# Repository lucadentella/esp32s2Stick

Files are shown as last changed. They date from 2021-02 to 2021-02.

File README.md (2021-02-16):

# esp32s2Stick
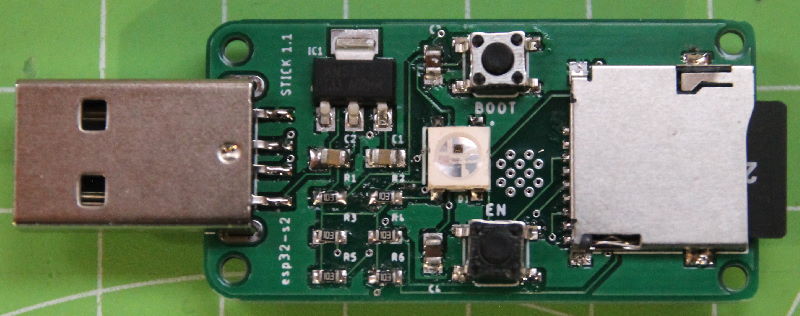
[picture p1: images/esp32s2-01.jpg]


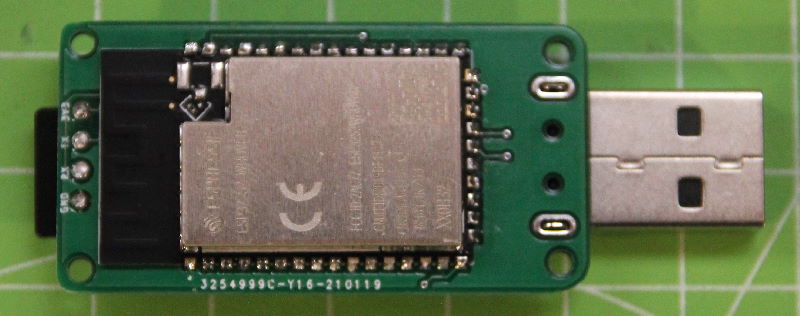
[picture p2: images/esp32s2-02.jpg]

## Description
esp32s2Stick is a USB device based on the **esp32-s2** chip by [Espressif](https://www.espressif.com/en/products/socs/esp32-s2).
Thanks to the presence of an USB OTG interface, it is possible to program the chip to act as a USB peripheral (*mass storage device*, *CDC*...) and to upgrade the firmware through USB (DFU, *Device Firmware Upgrade*).

In addition to the basic circuit needed to run the WROVER module, esp32s2Stick offers an **RGB LED** and a socket for **MicroSD** cards.
## How to make
- Blog post on [my website](http://www.lucadentella.it/en/2021/02/16/esp32s2stick/)
- Eagle files (schematic and board) are available in the "**eagle**" subfolder
- Some test *sketches* for Arduino are available in the "**arduino**" subfolder
- PCB can be ordered [from PCBWay](https://www.pcbway.com/project/shareproject/esp32s2Stick.html)
## Partlist 
 - **C1, C2**: 100nF SMD capacitor (0805)
 - **C3, C4**: 1uF SMD capacitor (0805)
 - **R1, R2, R3, R4, R5, R6**: 10Kohm SMD resistor (0603)
 - **IC1**: 1117-3.3 voltage regulator
 - **D1**: WS2812 RGB led (5050, 4 pins)
 - **BOOT, EN**: SMD momentary switch (5.2mm)
 - **U1**: ESP32-S2-WROVER
 - **J1**: USB A male SMD connector
 - **P1**: MicroSD card socket

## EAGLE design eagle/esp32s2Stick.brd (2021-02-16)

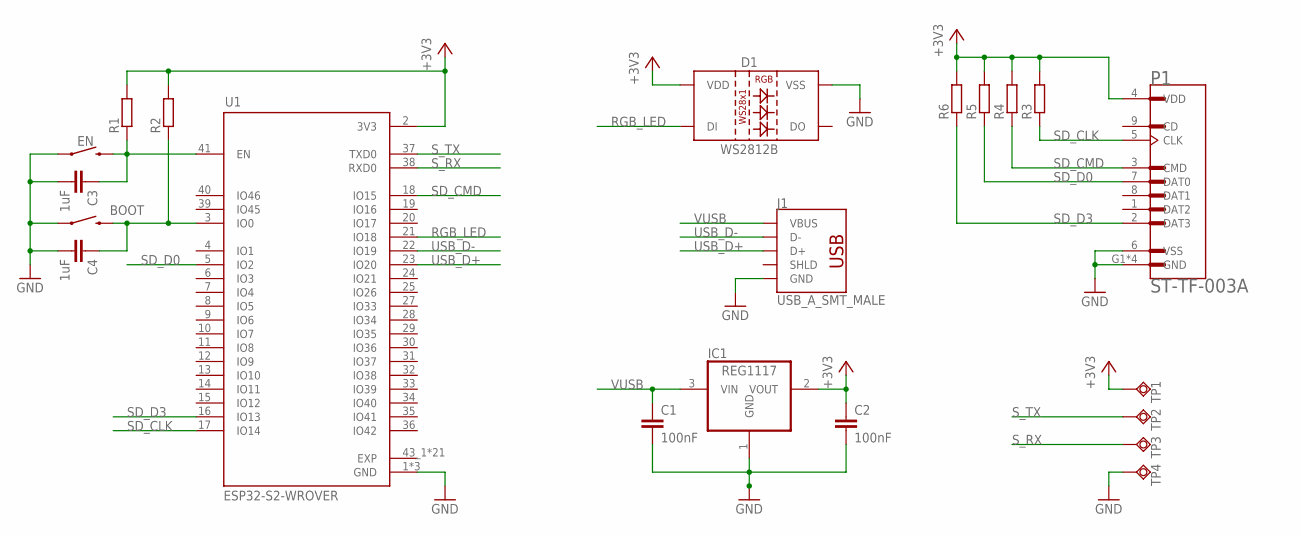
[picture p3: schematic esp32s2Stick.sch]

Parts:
BOOT: MOMENTARY-SWITCH-SPST-SMD-5.2MM; TACTILE_SWITCH_SMD_5.2MM
C1, C2: 100nF; C0805
C3, C4: 1uF; C0805
D1: WS2812B
EN: MOMENTARY-SWITCH-SPST-SMD-5.2MM; TACTILE_SWITCH_SMD_5.2MM
IC1: REG1117; SOT223
J1: USB_A_SMT_MALE; USB-A-SMT-MALE
P1: ST-TF-003A; SUNTECH_ST-TF-003A
R1, R2, R3, R4, R5, R6: R-EU_R0603; R0603
TP1, TP2, TP3, TP4: TPSQTP15R; TP15R
U1: ESP32-S2-WROVER; MODULE_ESP32-S2-WROVER

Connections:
+3V3: C2.1, D1.1 (VDD), IC1.2 (VOUT), P1.4 (VDD), R1.2, R2.2, R3.2, R4.2, R5.2, R6.2, TP1.TP, U1.2 (3V3)
EXP: U1.43_1 (EXP), U1.43_2 (EXP), U1.43_3 (EXP), U1.43_4 (EXP), U1.43_5 (EXP), U1.43_6 (EXP), U1.43_7 (EXP), U1.43_8 (EXP), U1.43_9 (EXP), U1.43_10 (EXP), U1.43_11 (EXP), U1.43_12 (EXP), U1.43_13 (EXP), U1.43_14 (EXP), U1.43_15 (EXP), U1.43_16 (EXP), U1.43_17 (EXP), U1.43_18 (EXP), U1.43_19 (EXP), U1.43_20 (EXP), U1.43_21 (EXP)
GND: BOOT.1, C1.2, C2.2, C3.2, C4.2, D1.3 (VSS), EN.1, IC1.1 (GND), J1.GND1 (GND), P1.6 (VSS), P1.G1 (GND), P1.G2 (GND), P1.G3 (GND), P1.G4 (GND), TP4.TP, U1.1 (GND), U1.26 (GND), U1.42 (GND)
unnamed: BOOT.3 (2), C4.1, R2.1, U1.3 (IO0)
unnamed: C3.1, EN.3 (2), R1.1, U1.41 (EN)
RGB_LED: D1.4 (DI), U1.21 (IO18)
SD_CLK: P1.5 (CLK), R3.1, U1.17 (IO14)
SD_CMD: P1.3 (CMD), R4.1, U1.18 (IO15)
SD_D0: P1.7 (DAT0), R5.1, U1.5 (IO2)
SD_D3: P1.2 (DAT3), R6.1, U1.16 (IO13)
S_RX: TP3.TP, U1.38 (RXD0)
S_TX: TP2.TP, U1.37 (TXD0)
USB_D+: J1.D+1 (D+), U1.23 (IO20)
USB_D-: J1.D-1 (D-), U1.22 (IO19)
VUSB: C1.1, IC1.3 (VIN), J1.VBUS1 (VBUS)

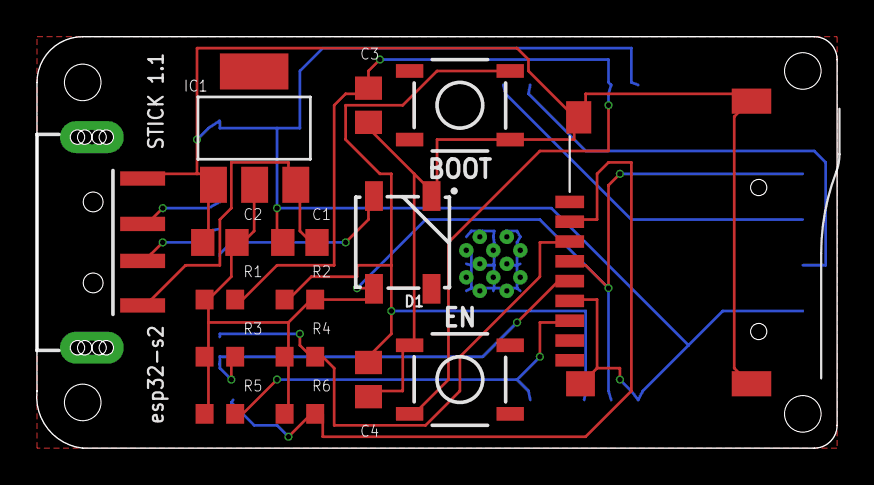
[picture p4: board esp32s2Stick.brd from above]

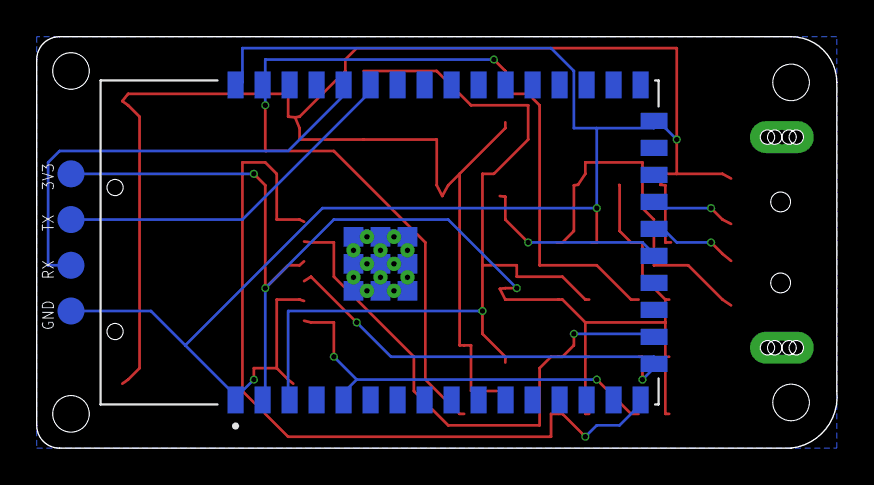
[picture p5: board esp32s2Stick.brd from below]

Board: 2 copper layers, 44.5 x 22.9 mm, 21 parts (5 on the bottom side), 15 nets.

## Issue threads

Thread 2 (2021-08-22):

REQUEST: Being able to order this fully assembled would be great!

Misterke, 2021-08-22:
Ordering the PCB, still leaves sourcing all components and then having to mount them.  I would love a couple of devices like this, but don't have the components, nor the tools or skills for SMD mounting.  So, having a design that could be ordered with all the SMD parts already soldered on and other components added to the package as offered by a.o. JLC PCB, could really help.  Or perhaps a Chinese partner producing an end-user product giving you a cut?

lucadentella, 2021-08-23:
Hi! Thanks for your comment... In the past I worked with some PCBA services but the minimum quantity was 20-30 pcs and honestly at the moment I don't have requests for pre-assembled boards (excluding your one ;) )

I checked with JLCPCB but they don't provide a "market", where I may upload design files, BoM... and let other users order my products. I may upload all the files required to order the boards directly using JLCPCB PCBA service, but be prepared because at least two components (the esp module and the usb connector) are "extended parts" and they require an extra fee to include them in your order... If you like, I may work on this tomorrow

sbhamad, 2022-06-18:
any update on the BoM? i would love to get the exact components to order the pcb myself.

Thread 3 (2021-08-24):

Code for complete

noorhaq, 2021-08-24:
Hi in the arduino part I can see the testing codes but not the code, which will actually make it work. Like PC and SD card will be accessible

lucadentella, 2021-08-25:
Hi! Please consider this project as a "devboard", not a final product. This is the reason why you can't find a code for a specific behavior... you can develop your own code (starting from my example but also using the "plain" esp framework) for your goal.
I know some users who worked on a code to simulate a keyboard and let the device "type" the content of a file on the SD or other users who implemented a "bridge" between a TCP socket and mouse movements.

Closed 2021-08-25.

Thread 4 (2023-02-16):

Ordered a couple of these from PCBWay, they don't seem to power up

cieslicki, 2023-02-16:
Edited: I think I got shipped a bad batch of USB connectors, or there is some PCB trace issue with power coming out of the connector. I soldered jumpers on power and ground to the debug pads, and then also directly to the D+/D- pins coming out of the connector, and it powers up and programs. But then after I program it and plug it back in with the regular connector, it won't power up.

original:

When I plug the device in, there is no indication it is powered up by the LED. Also the voltage regulator is cold. When I attempt to put it into DFU mode with the buttons, the Arduino IDE doesn't see it. I don't think these work at all. Maybe it is an assembly issue.

What is the expected behavior when the device gets plugged in?

lucadentella, 2023-02-16:
Hi

I only ordered PCBs from PCBWay so I can't tell how good they are in assembling the device. It definetly sounds an issue with their USB connector even if it's a very simple part (compared to the new USB-C connectors)

Let me know how it goes, did you try to replace the connector?

cieslicki, 2023-02-19:
Hi.

After further investigation I can say it's definitely not the connector that is the source of the problem.

1) I can plug it in and use a multimeter to read 5v from PWR to GND from the connector pins where they attach to the board.

2) I soldered an external LM1117 voltage regulator onto the debug pins, and ran jumpers back to 5v and GND at the connector pins, the module will power up and program with the board's main USB-A connector plugged into my laptop. So all four connector pins work.

I would say the board at least has power issues. For example, I don't see either a trace or a via at the connector ground pin. So I don't know that the board grounds, and I suspect it does not. I soldered in a jumper from the on-board voltage regulator ground to the connector ground, and it still did not fire up the board, so there are likely a collection of grounding issues.

I tried a couple of different jumper configurations to try to get the on-board voltage regulator to power the module, but nothing I tried worked there.

It's a cool idea to get the SD card reader on a board with the ESP, and with the additional voltage regulator I might still be able to test out the SD functionality, but out of the box as it is right now the board is not really viable as far as I can tell. Additionally with the antenna blocked by the PCB I can't even pick up the signal from the ESP in AP mode using the laptop it is plugged in to. I might suggest perhaps marking the listing on PCBWay with some caveats so people know what they are getting into.

lucadentella, 2023-02-20:
Hi

I made a few of these boards (by myself, not using PCBway assembly service) and they work fine.
I also contacted some users which in the past asked me for files... and they also were able to build some boards without issues.

The connector GND pin should be connected via thermals to the ground plane and you should be able to test using a multimeter that it is also connected to other GND pins (regulator, debug...).

I suspect that something went wrong during the assembly... maybe they used the wrong voltage regulator (which has a different pin layout)? Unfortunately I've no control on what PCBway does (I only uploaded the gerber files for PCB manufacturing).

cieslicki, 2023-02-23:
Apologies, my error on the grounding. I see now how it grounds.

It actually looks like the voltage regulators on the boards are producing 2.5v, and not 3.3v, which would explain why they don't seem to power up when plugged in, but do power up when I solder on an external known-good 3v3 voltage regulator onto the debug pads.

From the regulator's Vin to GND at the connector pin I read 5v, which is expected and should tell us that the regulator is getting the full 5v from the connector.

However, from the regulator's Vout to GND at the connector, I read 2.4 - 2.5v, depending on which of the several boards I was shipped.

The regulators on the boards are labeled
BB1117
232GX4H

Reading that datasheet, it looks like BB1117 corresponds to the adjustable voltage version https://www.ti.com/lit/ds/sbvs001d/sbvs001d.pdf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

The adjustable voltage version uses resistors to set the output voltage, but interestingly none of the specified resistor combinations in the datasheet would produce 2.4-2.5v. I would imagine that you would have originally laid out the board expecting a standard 3.3v regulator?

When I look at the BOM on the order, the voltage regulator is specified as REG1117 (the adjustable voltage part) when I would have expected REG1117-3.3, the 3.3v part.

And, as mentioned, with an external 3.3v regulator attached at debug pads, the board does power and program.

Maybe this will be a good excuse for me to purchase re-work tools, so I can replace the regulators.

Thanks for chatting.

lucadentella, 2023-02-24:
thanks: I confirm that IC1 is a **fixed**, 3.3V regulator

Closed 2023-02-23.

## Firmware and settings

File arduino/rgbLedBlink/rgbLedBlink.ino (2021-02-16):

#include <Adafruit_NeoPixel.h>

Adafruit_NeoPixel strip(1, 18, NEO_GRB + NEO_KHZ800);


void setup() {

  Serial.begin(115200);
  Serial.println("rgbLedBlink");
  strip.begin();
  strip.setBrightness(10);
  strip.clear();
}

void loop() {

  delay(500);
  strip.setPixelColor(0, 255, 0, 0);
  strip.show();
  delay(500);
  strip.setPixelColor(0, 0, 255, 0);
  strip.show();
  delay(500);
  strip.setPixelColor(0, 0, 0, 255);
  strip.show();
}

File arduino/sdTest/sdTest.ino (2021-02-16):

#include "SD.h"
#include "SPI.h"

#define HSPI_MISO   2
#define HSPI_MOSI   15
#define HSPI_SCLK   14
#define HSPI_SS     13

SPIClass *spi = NULL;

void setup() {
  
  Serial.begin(115200);

  spi = new SPIClass(HSPI);
  spi->begin(HSPI_SCLK, HSPI_MISO, HSPI_MOSI, HSPI_SS);
  pinMode(HSPI_SS, OUTPUT);
  
  if(!SD.begin(HSPI_SS, *spi)){
      Serial.println("Card Mount Failed");
      return;
  }
  uint8_t cardType = SD.cardType();
  
  if(cardType == CARD_NONE){
      Serial.println("No SD card attached");
      return;
  }
  
  Serial.print("SD Card Type: ");
  if(cardType == CARD_MMC){
      Serial.println("MMC");
  } else if(cardType == CARD_SD){
      Serial.println("SDSC");
  } else if(cardType == CARD_SDHC){
      Serial.println("SDHC");
  } else {
      Serial.println("UNKNOWN");
  }
  
  uint64_t cardSize = SD.cardSize() / (1024 * 1024);
  Serial.printf("SD Card Size: %lluMB\n", cardSize);
}

void loop() {
  // put your main code here, to run repeatedly:

}

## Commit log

2021-02-16 Eagle files added
    [esp32s2Stick.brd, esp32s2Stick.sch]
2021-02-16 Arduino examples added

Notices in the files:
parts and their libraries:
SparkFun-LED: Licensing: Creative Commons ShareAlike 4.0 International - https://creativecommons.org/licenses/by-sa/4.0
